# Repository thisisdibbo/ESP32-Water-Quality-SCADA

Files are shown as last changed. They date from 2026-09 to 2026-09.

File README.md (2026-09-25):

# WaterSCADA — ESP32 Water-Quality Logger

GPS-tagged water-quality logger built on an ESP32. It measures **TDS / EC** and **water temperature**, stamps every reading with **RTC time** and **GPS position**, logs it to a **microSD card**, and streams it over USB to **WaterSCADA** — a PyQt6 desktop dashboard with live gauges, a map and trend charts.







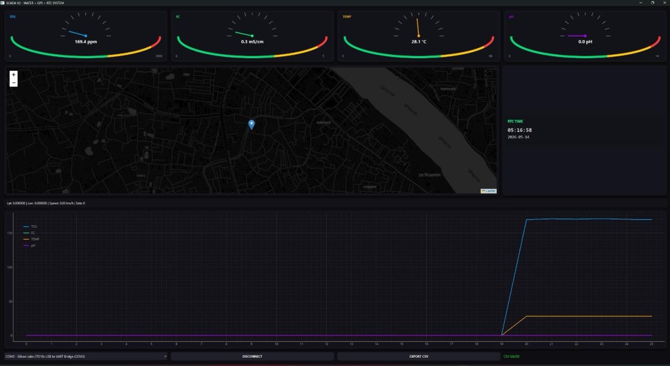
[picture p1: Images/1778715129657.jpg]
WaterSCADA dashboard


| Assembled board | Prototype enclosure |
| :---: | :---: |
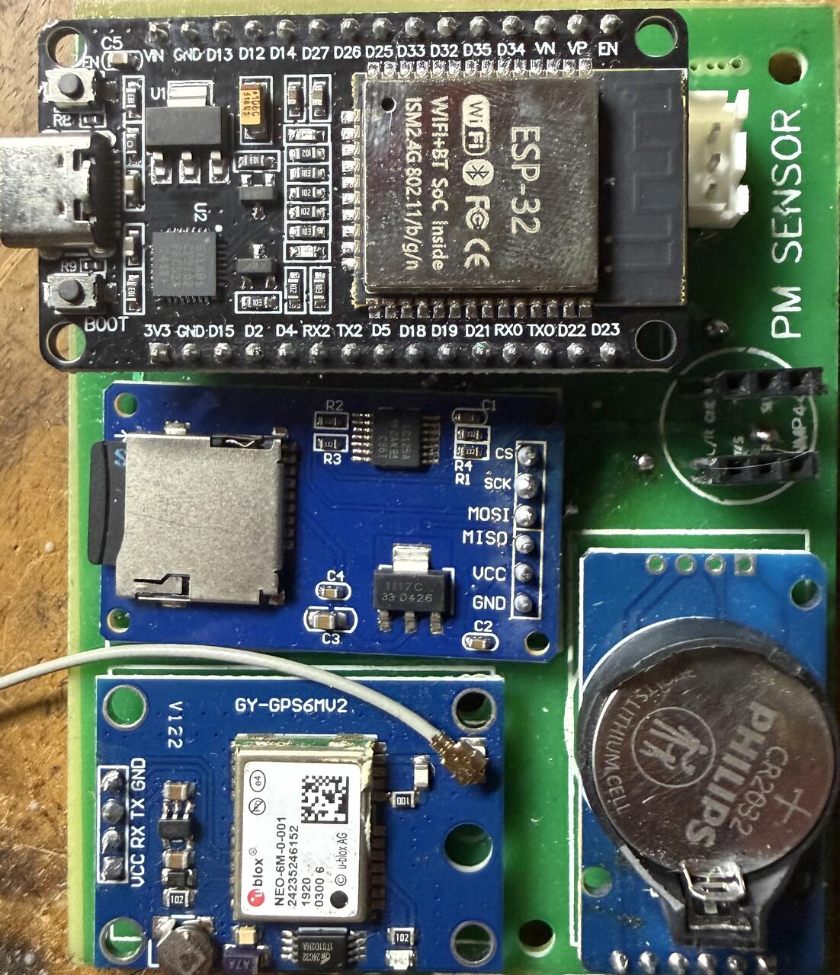
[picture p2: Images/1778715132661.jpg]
ESP32 carrier board with microSD, NEO-6M GPS and DS3231 RTC modules
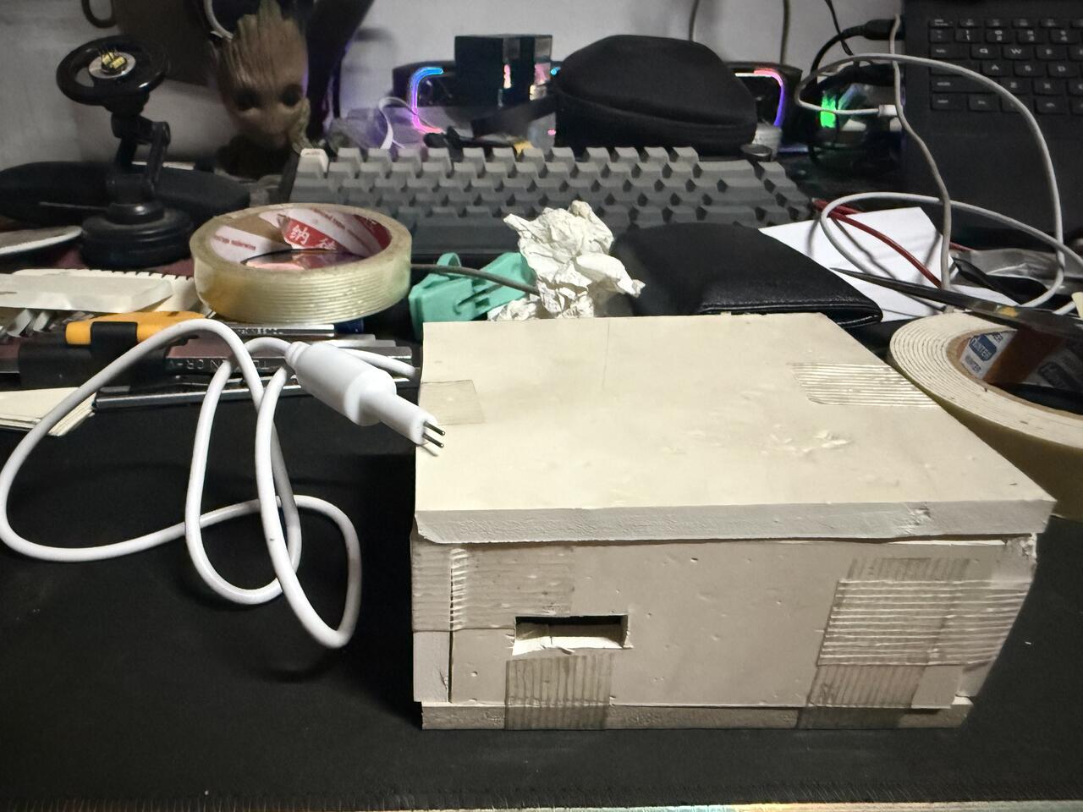
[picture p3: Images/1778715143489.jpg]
Prototype enclosure with probe
|  |  |

---

## Features

- **Water quality** — TDS (ppm) and EC (mS/cm) from an analog TDS probe, 20-sample averaged ADC
- **Water temperature** — DS18B20 waterproof probe, 5-reading average
- **Location** — NEO-6M GPS: latitude, longitude, speed and satellite count
- **Time** — DS3231 RTC with coin-cell backup
- **Stand-alone logging** — every reading is appended to `water_log.csv` on the microSD card
- **Live dashboard** — animated gauges (TDS, EC, temperature, pH), dark map with GPS track, RTC clock, rolling trend chart, one-click CSV export
- **Windows app** — packaged as a single `WaterSCADA.exe` with PyInstaller

## How it works

```mermaid
flowchart LR
    TDS["TDS Meter V1.0<br/>analog · GPIO33"] --> ESP
    TEMP["DS18B20 probe<br/>1-Wire · GPIO16"] --> ESP
    GPS["GY-NEO6MV2 GPS<br/>UART · GPIO4 / GPIO2"] --> ESP
    RTC["DS3231 RTC<br/>I²C · GPIO21 / GPIO22"] --> ESP
    ESP["ESP32 DevKit V1"] -->|"SPI"| SD[("microSD<br/>water_log.csv")]
    ESP -->|"USB serial · 115200 baud"| APP["WaterSCADA<br/>PyQt6 dashboard"]
    APP --> CSV[("CSV export")]
```

Each cycle (about 8–9 s, mostly the 5-sample DS18B20 average) the firmware reads every sensor, appends a row to the SD card and prints one CSV line over USB. The dashboard parses that line and updates the gauges, map, clock and chart.

## Hardware

| Qty | Part | Used for |
| :-: | --- | --- |
| 1 | ESP32 DevKit V1 — 30-pin, ESP32-WROOM-32, CP210x USB-UART | Controller |
| 1 | TDS Meter V1.0 board + TDS probe | TDS / EC |
| 1 | DS18B20 waterproof probe + 10 kΩ resistor | Water temperature |
| 1 | GY-NEO6MV2 (u-blox NEO-6M) + antenna | Position and speed |
| 1 | DS3231 RTC module + CR2032 cell | Timestamps |
| 1 | MicroSD card module (SPI) + FAT32 microSD card | Local logging |
| 1 | Carrier PCB and enclosure | Mounting |

### Wiring

Pin map, as used by the firmware and drawn in the Fritzing diagram:

| Module | Module pin | ESP32 pin | Notes |
| --- | --- | --- | --- |
| TDS Meter V1.0 | A | GPIO33 (D33) | ADC1 channel 5 |
| DS18B20 | DQ | GPIO16 (RX2) | 10 kΩ pull-up to 3V3 |
| GY-NEO6MV2 | TX | GPIO4 (D4) | UART1 RX, 9600 baud |
| GY-NEO6MV2 | RX | GPIO2 (D2) | UART1 TX |
| DS3231 | SDA / SCL | GPIO21 / GPIO22 | I²C |
| microSD | CS / SCK / MISO / MOSI | GPIO5 / GPIO18 / GPIO19 / GPIO23 | SPI (VSPI) |

**Power (recommended):** common GND for everything. Run the DS18B20 (and its pull-up), the DS3231 and the TDS board from **3V3**. The microSD module has an onboard AMS1117 regulator, so feed it **5 V from VIN**. The GY-NEO6MV2 accepts 3.3–5 V.

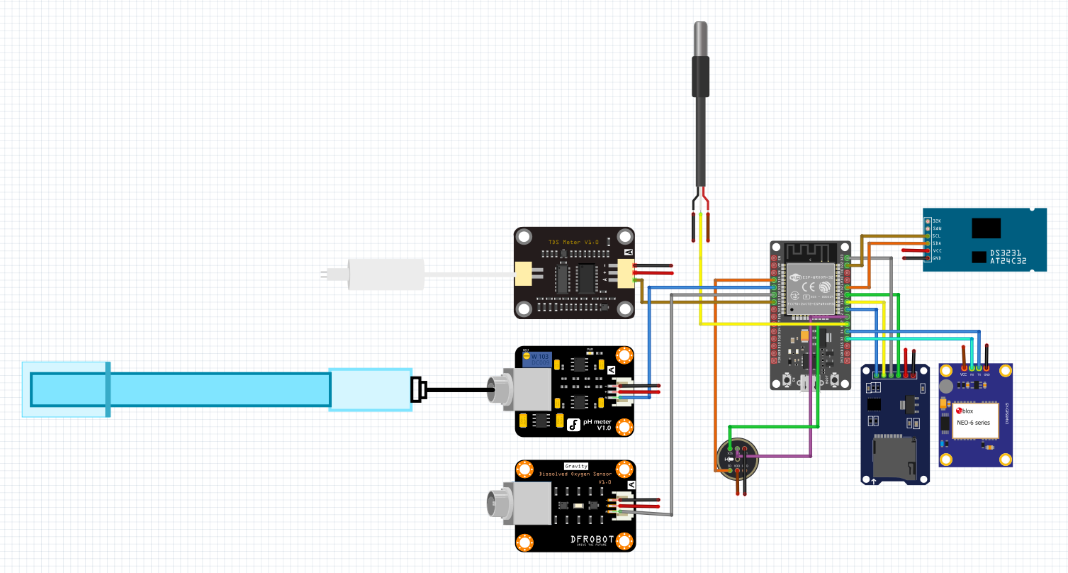
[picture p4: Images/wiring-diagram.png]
Fritzing wiring diagram


> [!NOTE]
> The Fritzing file [`Diagram/water monitor.fzz`](Diagram/water%20monitor.fzz) also includes a DFRobot pH meter (SEN0161, A → GPIO35), a DFRobot Gravity dissolved-oxygen sensor (SEN0237-A, A → GPIO32) and an INMP441 I²S microphone. The current firmware does not read them yet, so the dashboard's pH gauge stays at 0.0.

## Repository layout

```text
├── Code for Arduino/
│   └── waaterloggerpython/
│       └── waaterloggerpython.ino   ESP32 firmware
├── Diagram/
│   └── water monitor.fzz            Fritzing wiring diagram
├── Images/                          photos, dashboard screenshot, wiring diagram
├── main.py                          WaterSCADA dashboard (PyQt6)
├── WaterSCADA.spec                  PyInstaller build recipe
├── app.ico                          application icon
├── requirements.txt                 Python dependencies
└── LICENSE
```

## Getting started

### 1. Flash the firmware

1. Install **Arduino IDE 2.x** and add ESP32 support: *Boards Manager →* **esp32** by Espressif Systems.
2. From *Library Manager*, install:
   - **RTClib** by Adafruit (accept the *Adafruit BusIO* dependency)
   - **TinyGPSPlus** by Mikal Hart
   - **OneWire**
   - **DallasTemperature** by Miles Burton

   `SD`, `SPI`, `Wire` and `HardwareSerial` come with the ESP32 core.
3. Open [`Code for Arduino/waaterloggerpython/waaterloggerpython.ino`](Code%20for%20Arduino/waaterloggerpython/waaterloggerpython.ino).
4. Select *Tools → Board →* **ESP32 Dev Module** (or *DOIT ESP32 DEVKIT V1*), pick the COM port and click **Upload**.
5. Insert a FAT32 microSD card and open the Serial Monitor at **115200 baud**. You should see `SYSTEM READY`, then a reading every few seconds.

**Setting the RTC.** The sketch only reads the DS3231. To set it from your PC clock, add this line in `setup()` right after `rtc.begin()`, upload once, then delete the line and upload again (otherwise every reset rewinds the clock to the compile time):

```cpp
rtc.adjust(DateTime(F(__DATE__), F(__TIME__)));
```

### 2. Run the dashboard

Needs Python 3.10 or newer (developed on Python 3.14, Windows).

```powershell
python -m venv .venv
.venv\Scripts\activate
pip install -r requirements.txt
python main.py
```

1. Plug in the ESP32 **before** starting the app — the COM-port list is read at launch.
2. Pick the port (for example `COM3 - Silicon Labs CP210x USB to UART Bridge`) and click **CONNECT ESP32**.
3. **EXPORT CSV** saves everything received in the session. **Esc** toggles full screen.

The map (Leaflet with CARTO dark tiles) needs an internet connection; everything else works offline.

### 3. Build the Windows executable (optional)

```powershell
pip install pyinstaller
pyinstaller WaterSCADA.spec
```

The single-file app is written to `dist/WaterSCADA.exe` (about 230 MB, because it bundles Qt WebEngine for the map). A prebuilt copy is on the [Releases](../../releases) page.

## Data formats

**USB serial (115200 baud).** Each cycle prints a readable block followed by one CSV line, which is what the dashboard parses:

| Field | Unit / format | Notes |
| --- | --- | --- |
| `tds` | ppm | |
| `ec` | mS/cm | |
| `temp` | °C | `0.00` if the DS18B20 is not detected |
| `ph` | — | always `0.00` for now |
| `time` | `YYYY-MM-DD HH:MM:SS` | from the DS3231 |
| `lat`, `lon` | degrees | `0.000000` until the GPS has a fix |
| `speed` | km/h | |
| `sats` | count | satellites used in the fix |

Example line:

```text
169.40,0.34,28.12,0.00,2026-05-14 05:16:58,0.000000,0.000000,0.00,0
```

**microSD card (`/water_log.csv`).** Columns `Time,ADC,Voltage,EC,TDS,Temp,Lat,Lon,Speed,Sats`, one row per cycle. The raw ADC value and probe voltage are kept so the data can be recalibrated later.

**Dashboard export.** Columns `Time,TDS,EC,TEMP,pH,RTC,Lat,Lon,Speed,Sats`. `Time` is the PC clock; `RTC` is the logger's clock.

## TDS / EC calculation

```text
V   = ADC × 3.3 / 4095                             mean of 20 samples, 12-bit ADC
EC  = (133.42·V³ − 255.86·V² + 857.39·V) / 1000    mS/cm
TDS = EC × 500                                     ppm (conversion factor 0.5)
```

The cubic is the standard curve for DFRobot-style analog TDS boards.

**Known limitations**

- EC and TDS are not temperature-compensated yet (values are not normalised to 25 °C).
- `analogRead()` returns raw ESP32 ADC counts, which are non-linear; calibrate against a reference solution for accurate numbers.
- pH is a placeholder in the firmware (always 0.0).

## Troubleshooting

| Problem | Fix |
| --- | --- |
| No COM port in the app | Install the Silicon Labs CP210x driver, plug in the board, then restart the app |
| Upload fails with `Failed to connect to ESP32` | Hold **BOOT** when `Connecting...` appears. GPIO2 (GPS RX) is a boot-strapping pin, so unplug the GPS if it keeps failing |
| GPS stays at `0.000000` with 0 satellites | It needs open sky, and a cold start can take a few minutes. Check GPS TX → GPIO4 and RX → GPIO2 |
| Temperature shows `Not detected` or 0 °C | Check the probe wiring and the 10 kΩ pull-up between DQ and 3V3 |
| `SD Failed` at boot | Use a FAT32 card, check CS on GPIO5, and power the module from 5 V |
| RTC shows `2000-01-01` | Set the clock (see *Setting the RTC*) |
| Map is blank | The map tiles load from the internet |

## Author

**Md. Mahin Rahman** — [@thisisdibbo](https://github.com/thisisdibbo) · [mr.d2003feb@gmail.com](mailto:mr.d2003feb@gmail.com)\
Department of Electrical and Electronic Engineering, Islamic University of Technology (IUT), Gazipur, Bangladesh

## License

Released under the [MIT License](LICENSE).

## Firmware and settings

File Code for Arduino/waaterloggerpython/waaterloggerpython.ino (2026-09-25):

#include <Wire.h>
#include <SPI.h>
#include <SD.h>
#include <RTClib.h>
#include <TinyGPSPlus.h>
#include <HardwareSerial.h>

#include <OneWire.h>
#include <DallasTemperature.h>

// ================= PINS =================
#define TDS_PIN 33
#define SD_CS   5

#define GPS_RX 4
#define GPS_TX 2

#define TEMP_PIN 16   // DS18B20 (10k pull-up used externally)

// ================= GPS =================
HardwareSerial gpsSerial(1);
TinyGPSPlus gps;

// ================= RTC =================
RTC_DS3231 rtc;
File logFile;

// ================= TEMP SENSOR =================
OneWire oneWire(TEMP_PIN);
DallasTemperature sensors(&oneWire);

// ================= SETUP =================
void setup() {

  Serial.begin(115200);

  analogReadResolution(12);
  pinMode(TDS_PIN, INPUT);

  pinMode(TEMP_PIN, INPUT_PULLUP);

  Wire.begin(21, 22);

  if (!rtc.begin()) {
    Serial.println("❌ RTC not found");
  } else {
    Serial.println("✅ RTC Ready");
  }

  gpsSerial.begin(9600, SERIAL_8N1, GPS_RX, GPS_TX);
  Serial.println("✅ GPS Started");

  SPI.begin(18, 19, 23, SD_CS);

  if (!SD.begin(SD_CS)) {
    Serial.println("❌ SD Failed");
  } else {
    Serial.println("✅ SD Ready");

    logFile = SD.open("/water_log.csv", FILE_APPEND);

    if (logFile && logFile.size() == 0) {
      logFile.println("Time,ADC,Voltage,EC,TDS,Temp,Lat,Lon,Speed,Sats");
      logFile.close();
    }
  }

  sensors.begin();
  Serial.println("✅ DS18B20 Ready");

  Serial.println("SYSTEM READY");
}

// ================= TIME FUNCTION =================
String getTime() {

  DateTime now = rtc.now();

  char buf[25];

  sprintf(buf,
          "%04d-%02d-%02d %02d:%02d:%02d",
          now.year(),
          now.month(),
          now.day(),
          now.hour(),
          now.minute(),
          now.second());

  return String(buf);
}

// ================= STABLE TEMP READ =================
float readTemperature() {

  float sum = 0;
  int valid = 0;

  for (int i = 0; i < 5; i++) {

    sensors.requestTemperatures();
    delay(750);

    float t = sensors.getTempCByIndex(0);

    if (t != DEVICE_DISCONNECTED_C && t > -55 && t < 125) {
      sum += t;
      valid++;
    }

    delay(100);
  }

  if (valid == 0) return DEVICE_DISCONNECTED_C;

  return sum / valid;
}

// ================= LOOP =================
void loop() {

  while (gpsSerial.available()) {
    gps.encode(gpsSerial.read());
  }

  float tempC = readTemperature();

  long sum = 0;

  for (int i = 0; i < 20; i++) {
    sum += analogRead(TDS_PIN);
    delay(5);
  }

  float adc = sum / 20.0;
  float voltage = adc * (3.3 / 4095.0);

  float ec = (133.42 * voltage * voltage * voltage
            - 255.86 * voltage * voltage
            + 857.39 * voltage);

  ec = ec / 1000.0;

  if (ec < 0) ec = 0;

  float tds = ec * 500.0;

  float lat = gps.location.isValid() ? gps.location.lat() : 0.0;
  float lon = gps.location.isValid() ? gps.location.lng() : 0.0;
  float speed = gps.speed.isValid() ? gps.speed.kmph() : 0.0;
  int sats = gps.satellites.isValid() ? gps.satellites.value() : 0;

  String timestamp = getTime();

  // ================= SERIAL OUTPUT (HUMAN READABLE) =================
  Serial.println("---------------------");

  Serial.print("Time: ");
  Serial.println(timestamp);

  Serial.print("TDS: ");
  Serial.print(tds);
  Serial.println(" ppm");

  Serial.print("EC: ");
  Serial.print(ec, 3);
  Serial.println(" mS/cm");

  Serial.print("Temp: ");
  if (tempC == DEVICE_DISCONNECTED_C) {
    Serial.println("❌ Not detected");
  } else {
    Serial.print(tempC);
    Serial.println(" °C");
  }

  Serial.print("GPS: ");
  Serial.print(lat, 6);
  Serial.print(", ");
  Serial.print(lon, 6);
  Serial.print(" | Speed: ");
  Serial.print(speed);
  Serial.print(" km/h | Sats: ");
  Serial.println(sats);

  // ================= SD LOG =================
  logFile = SD.open("/water_log.csv", FILE_APPEND);

  if (logFile) {

    logFile.print(timestamp); logFile.print(",");
    logFile.print(adc); logFile.print(",");
    logFile.print(voltage, 3); logFile.print(",");
    logFile.print(ec, 3); logFile.print(",");
    logFile.print(tds, 1); logFile.print(",");
    logFile.print(tempC); logFile.print(",");
    logFile.print(lat, 6); logFile.print(",");
    logFile.print(lon, 6); logFile.print(",");
    logFile.print(speed); logFile.print(","); logFile.println(sats);

    logFile.close();
  }

  // =========================================================
  // 🚀 PYTHON SCADA OUTPUT (EXTRA LINE - ADDED ONLY)
  // FORMAT:
  // tds,ec,temp,ph,time,lat,lon,speed,sats
  // =========================================================

  float ph = 0.0;

  if (tempC == DEVICE_DISCONNECTED_C) {
    tempC = 0.0;
  }

  Serial.print(tds);
  Serial.print(",");
  Serial.print(ec);
  Serial.print(",");
  Serial.print(tempC);
  Serial.print(",");
  Serial.print(ph);
  Serial.print(",");
  Serial.print(timestamp);
  Serial.print(",");
  Serial.print(lat, 6);
  Serial.print(",");
  Serial.print(lon, 6);
  Serial.print(",");
  Serial.print(speed);
  Serial.print(",");
  Serial.println(sats);

  delay(1000);
}

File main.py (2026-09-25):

import sys
import math
import csv
import serial
import serial.tools.list_ports
from datetime import datetime
from collections import deque

from PyQt6.QtWidgets import (
    QApplication, QMainWindow, QWidget,
    QPushButton, QComboBox, QLabel, QFileDialog,
    QHBoxLayout, QVBoxLayout, QFrame
)
from PyQt6.QtCore import Qt, QTimer, QPointF
from PyQt6.QtGui import QPainter, QColor, QPen, QFont
from PyQt6.QtWebEngineWidgets import QWebEngineView

import pyqtgraph as pg


# =========================
# BIKE METER GAUGE (SMOOTH NEEDLE + MIN/MAX)
# =========================
class CircularGauge(QWidget):
    def __init__(self, title, min_v, max_v, unit, color):
        super().__init__()
        self.title = title
        self.min_v = min_v
        self.max_v = max_v
        self.unit = unit
        self.color = QColor(color)
        self.value = 0
        self.display_value = 0  # smooth animation
        self.setMinimumSize(210, 180)

        # smooth animation timer
        self.anim = QTimer(self)
        self.anim.timeout.connect(self.animate)
        self.anim.start(30)

    def setValue(self, v):
        self.value = v

    def animate(self):
        # ease toward target value
        self.display_value += (self.value - self.display_value) * 0.15
        self.update()

    def paintEvent(self, e):
        p = QPainter(self)
        p.setRenderHint(QPainter.RenderHint.Antialiasing)

        rect = self.rect()
        center = rect.center()
        radius = min(rect.width(), rect.height()) // 2 + 10

        p.fillRect(rect, QColor(18, 18, 25))

        # base arc
        p.setPen(QPen(QColor(70, 70, 80), 8))
        p.drawArc(rect.adjusted(20, 20, -20, -10), 180 * 16, 180 * 16)

        # colored zones
        zones = [
            (0.0, 0.6, QColor(0, 220, 120)),
            (0.6, 0.85, QColor(255, 200, 0)),
            (0.85, 1.0, QColor(255, 60, 60)),
        ]
        for z0, z1, c in zones:
            p.setPen(QPen(c, 8))
            start = int(180 * 16 * z0)
            span = int(180 * 16 * (z1 - z0))
            p.drawArc(rect.adjusted(20, 20, -20, -10), 180 * 16 + start, span)

        # ratio
        ratio = (self.display_value - self.min_v) / (self.max_v - self.min_v)
        ratio = max(0, min(1, ratio))

        # needle
        angle = math.radians(180 + 180 * ratio)
        nx = center.x() + math.cos(angle) * (radius - 35)
        ny = center.y() + math.sin(angle) * (radius - 35)
        p.setPen(QPen(self.color, 3))
        p.drawLine(QPointF(center.x(), center.y()), QPointF(nx, ny))

        p.setBrush(self.color)
        p.setPen(Qt.PenStyle.NoPen)
        p.drawEllipse(center, 5, 5)

        # ticks
        p.setPen(QPen(QColor(120, 120, 140), 2))
        for i in range(0, 11):
            ang = math.radians(180 + (180 / 10) * i)
            x1 = center.x() + math.cos(ang) * (radius - 20)
            y1 = center.y() + math.sin(ang) * (radius - 20)
            x2 = center.x() + math.cos(ang) * (radius - 5)
            y2 = center.y() + math.sin(ang) * (radius - 5)
            p.drawLine(QPointF(x1, y1), QPointF(x2, y2))

        # digital value
        p.setPen(Qt.GlobalColor.white)
        p.setFont(QFont("Segoe UI", 13, QFont.Weight.Bold))
        p.drawText(rect.adjusted(0, 40, 0, 0), Qt.AlignmentFlag.AlignCenter,
                   f"{self.display_value:.1f} {self.unit}")

        # min/max labels
        p.setPen(QColor(160, 160, 180))
        p.setFont(QFont("Segoe UI", 8))
        p.drawText(10, rect.height() - 10, str(self.min_v))
        p.drawText(rect.width() - 35, rect.height() - 10, str(self.max_v))

        # title
        p.setPen(self.color)
        p.setFont(QFont("Segoe UI", 9, QFont.Weight.Bold))
        p.drawText(12, 20, self.title)


# =========================
# CARD CONTAINER (SHADOW)
# =========================
class Card(QFrame):
    def __init__(self):
        super().__init__()
        self.setStyleSheet("""
            QFrame {
                background: #14141c;
                border-radius: 12px;
            }
        """)
        self.setGraphicsEffect(self.shadow())

    def shadow(self):
        from PyQt6.QtWidgets import QGraphicsDropShadowEffect
        eff = QGraphicsDropShadowEffect()
        eff.setBlurRadius(18)
        eff.setXOffset(0)
        eff.setYOffset(4)
        eff.setColor(QColor(0, 0, 0, 150))
        return eff


# =========================
# RTC PANEL
# =========================
class RTCPanel(QFrame):
    def __init__(self):
        super().__init__()
        self.time = "--:--:--"
        self.date = "----‑--‑--"
        self.setFixedHeight(120)
        self.setStyleSheet("background:#121218;border-radius:12px;")

    def setRTC(self, ts):
        try:
            dt = datetime.strptime(ts, "%Y-%m-%d %H:%M:%S")
            self.time = dt.strftime("%H:%M:%S")
            self.date = dt.strftime("%Y-%m-%d")
        except:
            self.time = "--:--:--"
            self.date = "----‑--‑--"
        self.update()

    def paintEvent(self, e):
        p = QPainter(self)
        p.setRenderHint(QPainter.RenderHint.Antialiasing)
        p.fillRect(self.rect(), QColor(18, 18, 25))

        p.setPen(QColor(0, 255, 140))
        p.setFont(QFont("Segoe UI", 10, QFont.Weight.Bold))
        p.drawText(12, 30, "RTC TIME")

        p.setPen(Qt.GlobalColor.white)
        p.setFont(QFont("Consolas", 16))
        p.drawText(12, 65, self.time)
        p.setFont(QFont("Consolas", 11))
        p.drawText(12, 90, self.date)
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

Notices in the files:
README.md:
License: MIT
